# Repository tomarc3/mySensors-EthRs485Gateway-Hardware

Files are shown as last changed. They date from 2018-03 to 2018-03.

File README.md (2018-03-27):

# mySensors-EthRs485Gateway-Hardware

The mySensors-EthRs485Gateway-Hardware is a mySensors compatible Ethernet / RS485 gateway that is designed to fit in a DIN rail enclosure.

The PCB dimensions are designed to fit in a [CAMDENBOSS CNMB/2/KIT DIN](http://camdenboss.com/enclosures/din-rail-enclosures/cnmb-solid-top-kit) rail enclosure - with a litte mod... ;) 

The firmware that works with this gateway can be found at https://github.com/tomarc3/mySensors-EthRs485Gateway

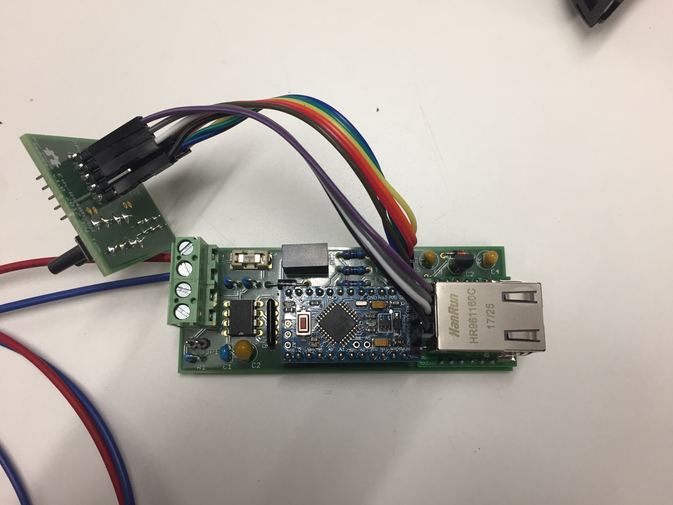
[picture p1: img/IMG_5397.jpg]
Top view

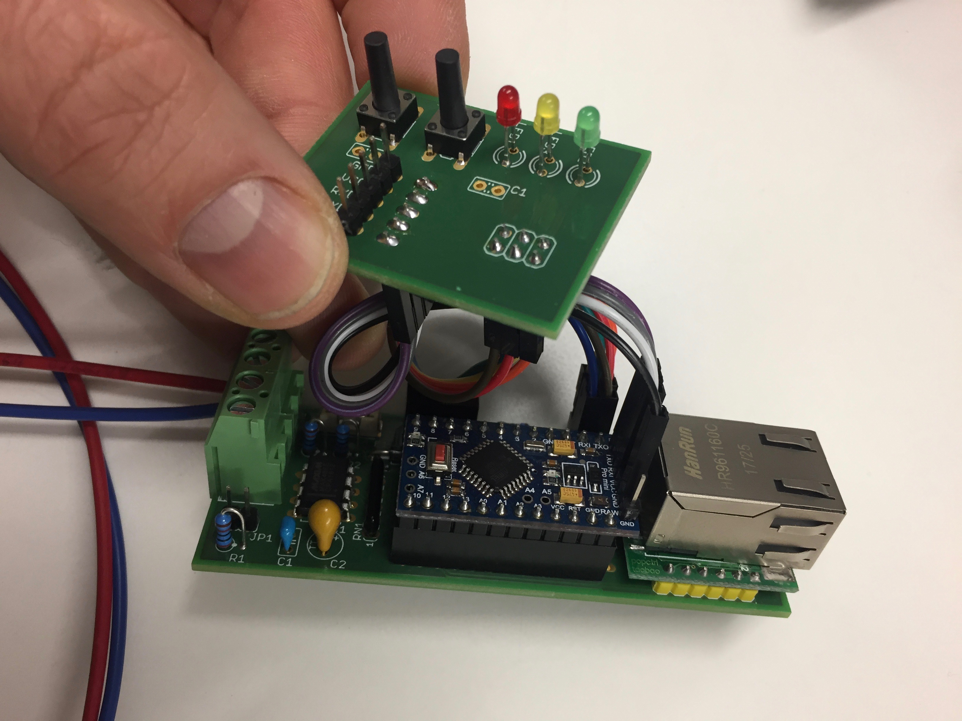
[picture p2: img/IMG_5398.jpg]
Side view


The front panel:
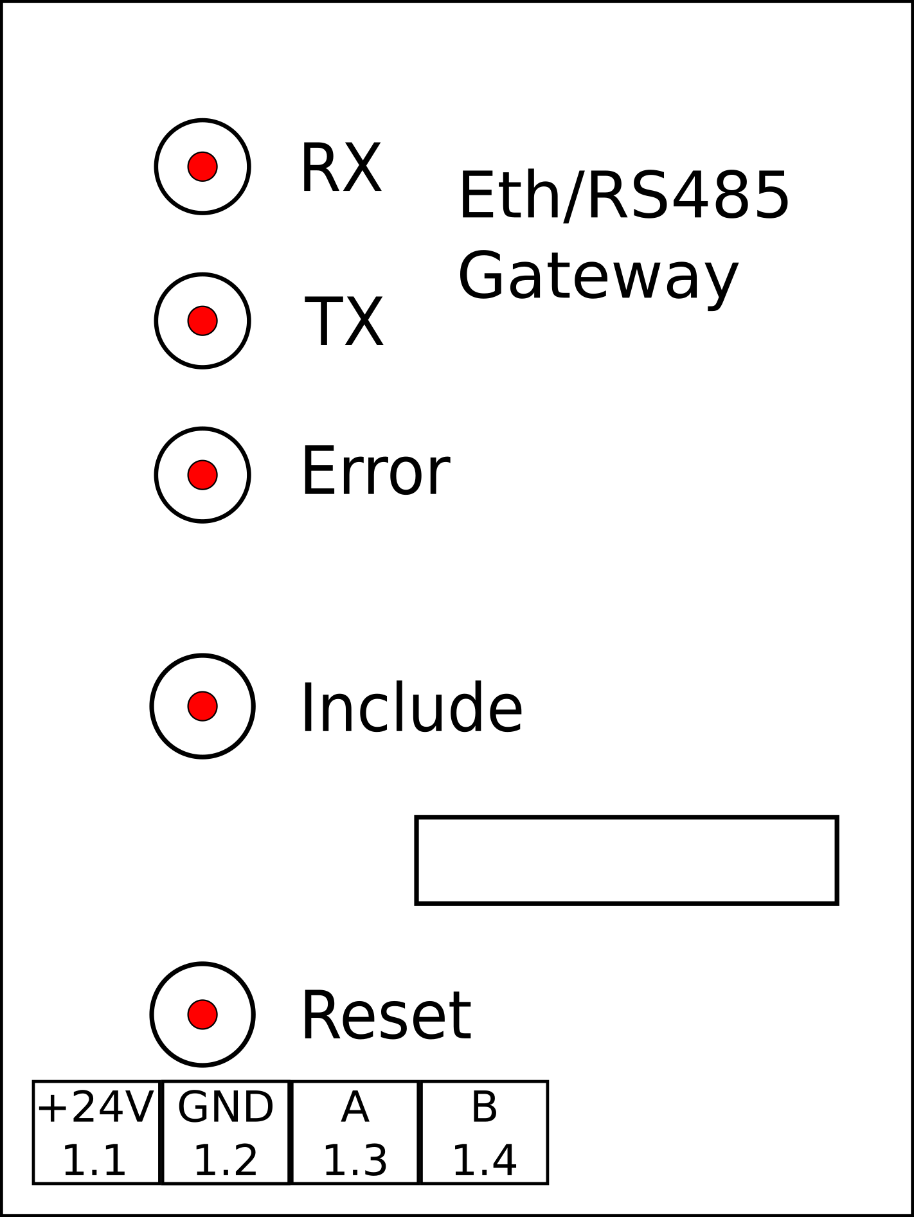
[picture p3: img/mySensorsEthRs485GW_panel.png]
Front panel


## Refereneces
* https://github.com/tomarc3/mySensors-EthRs485Gateway - the firmware built to run on this hardware
* https://www.mysensors.org - mySensors home page
* https://www.mysensors.org/build/rs485 - the example sketch that served as reference for this project 
* http://camdenboss.com/enclosures/din-rail-enclosures/cnmb-solid-top-kit - CAMDENBOSS CNMB/2/KIT DIN rail enclosure

## Change Log
* v1.0 ()
   Initial version.

## License
Copyright 2018 by Tom Kocher.

This documentation describes Open Hardware and is licensed under the CERN OHL v.1.2.

You may redistribute and modify this documentation under the terms of the CERN OHL v.1.2. (http://ohwr.org/cernohl). This documentation is distributed WITHOUT ANY EXPRESS OR IMPLIED WARRANTY, INCLUDING OF MERCHANTABILITY, SATISFACTORY QUALITY AND FITNESS FOR A PARTICULAR PURPOSE. Please see the CERN OHL v.1.2 for applicable conditions

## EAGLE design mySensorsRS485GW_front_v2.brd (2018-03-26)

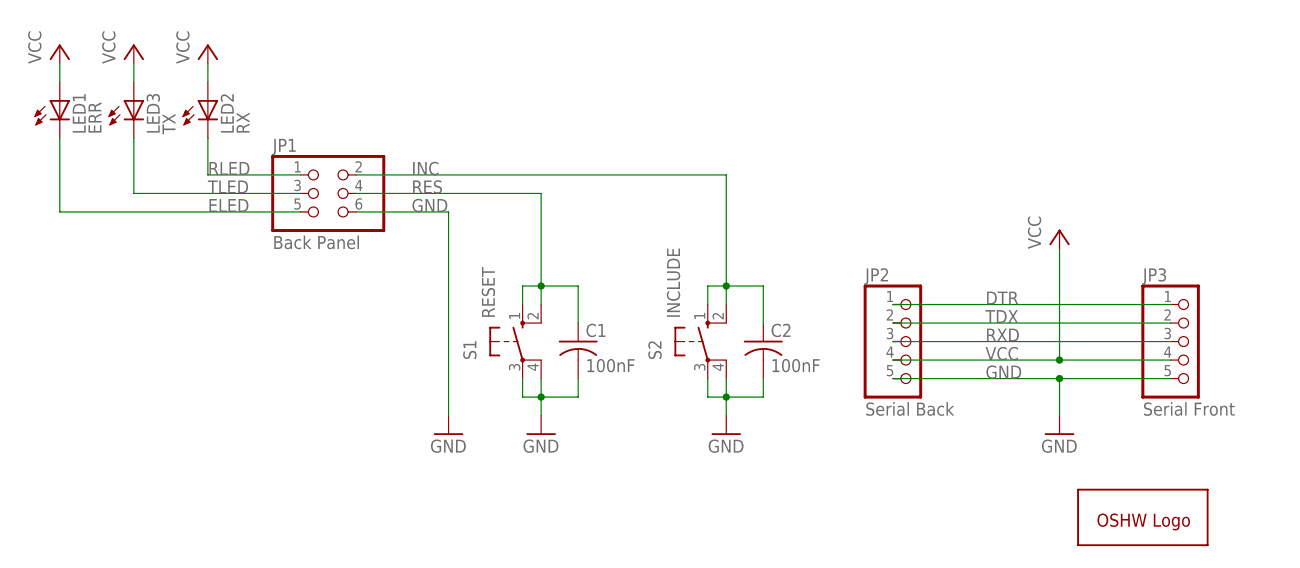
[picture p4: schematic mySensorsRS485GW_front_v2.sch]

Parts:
C1, C2: 100nF; C025-025X050
GOLD_ORB_SM1: OSHWLOGOLOGO5MM; OSHW_5MM
JP1: Back Panel; 2X03
JP2: Serial Back; 1X05
JP3: Serial Front; 1X05
LED1: ERR; LED3MM
LED2: RX; LED3MM
LED3: TX; LED3MM
S1: RESET; B3F-10XX
S2: INCLUDE; B3F-10XX

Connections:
DTR: JP2.1, JP3.1
ELED: JP1.5, LED1.K (C)
GND: C1.2, C2.2, JP1.6, JP2.5, JP3.5, S1.3, S1.4 (P1), S2.3, S2.4 (P1)
INC: C2.1, JP1.2, S2.1 (S), S2.2 (S1)
RES: C1.1, JP1.4, S1.1 (S), S1.2 (S1)
RLED: JP1.1, LED2.K (C)
RXD: JP2.3, JP3.3
TDX: JP2.2, JP3.2
TLED: JP1.3, LED3.K (C)
VCC: JP2.4, JP3.4, LED1.A, LED2.A, LED3.A

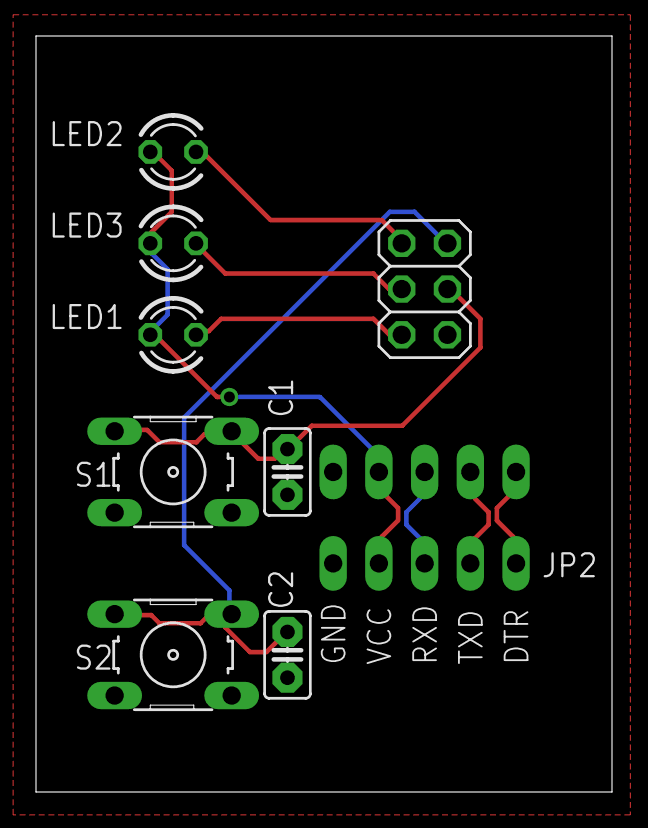
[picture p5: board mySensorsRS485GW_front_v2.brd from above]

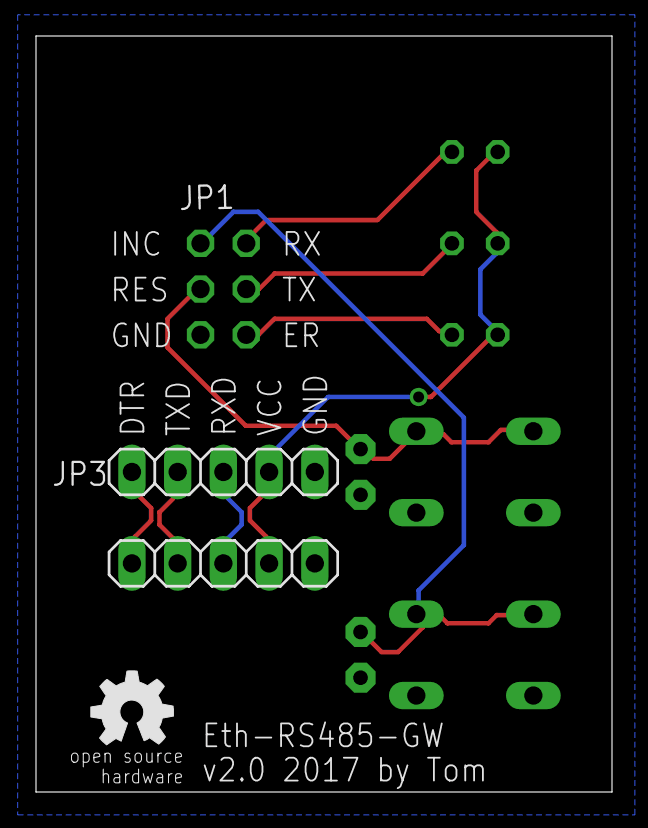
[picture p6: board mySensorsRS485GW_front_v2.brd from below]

Board: 2 copper layers, 32.0 x 42.0 mm, 11 parts (3 on the bottom side), 10 nets.

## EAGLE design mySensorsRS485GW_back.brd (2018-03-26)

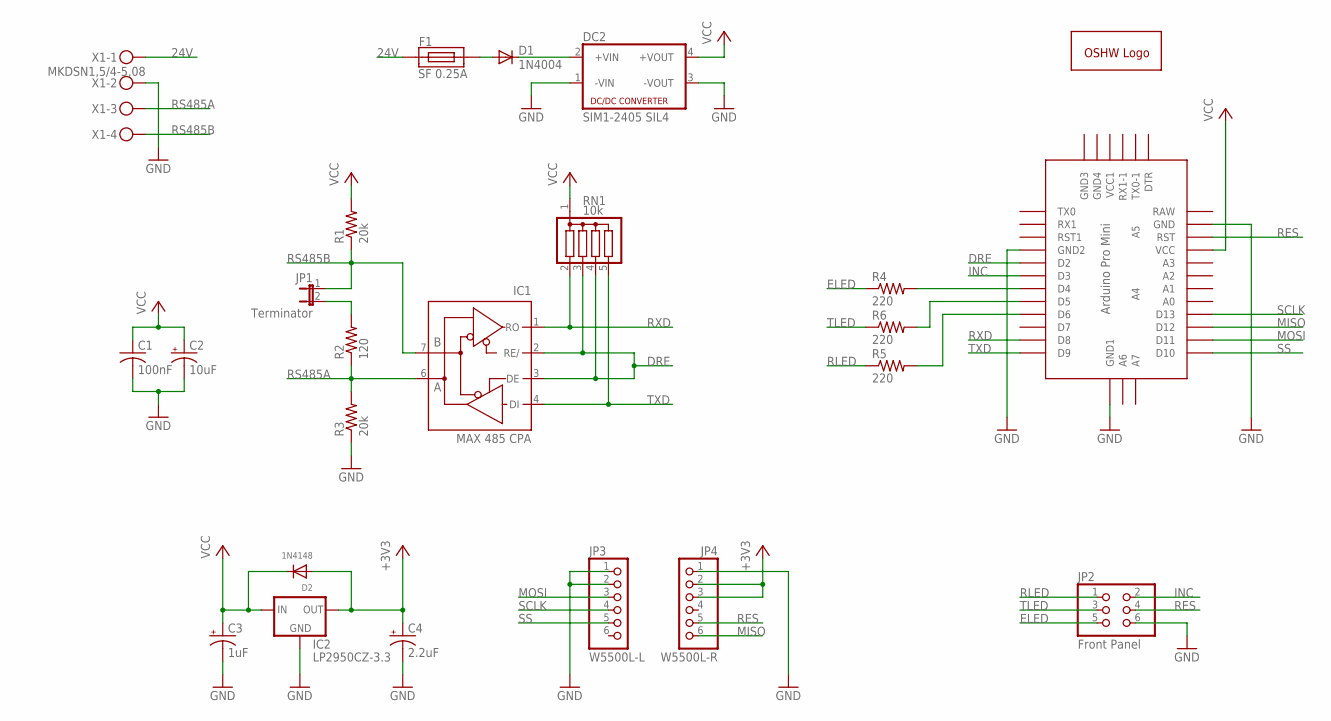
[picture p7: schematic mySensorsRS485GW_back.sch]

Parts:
C1: 100nF; C025-025X050
C2: 10uF; TT2D5
C3: 1uF; TT2D5
C4: 2.2uF; TT2D5
D1: 1N4004; DO41-10
D2: 1N4148; DO-1N4148
DC2: SIM1-2405 SIL4; NME
F1: SF 0.25A; NANO2_SMF_FUSEBLOCK
GOLD_ORB_SM1: OSHWLOGOLOGO5MM; OSHW_5MM
IC1: MAX 485 CPA; DIL08
IC2: LP2950CZ-3.3; TO92
JP1: Terminator; JP1
JP2: Front Panel; 2X03
JP3: W5500L-L; 1X06
JP4: W5500L-R; 1X06
R1, R3: 20k; 0207/2V
R2: 120; 0207/2V
R4, R5, R6: 220; 0207/7
RN1: 10k; SIL5
U$1: ABK-PRO-MINI
X1: MKDSN1,5/4-5,08

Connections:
24V: F1.1, X1.1
+3V3: C4.+, D2.A, IC2.1 (OUT), JP4.2, JP4.3
DRE: IC1.2 (RE/), IC1.3 (DE), RN1.3, RN1.4, U$1.D2
ELED: JP2.5, R4.1
GND: C1.2, C2.-, C3.-, C4.-, DC2.1 (-VIN), DC2.3 (-VOUT), IC1.5 (GND), IC2.2 (GND), JP2.6, JP3.1, JP3.2, JP4.1, R3.1, U$1.GND, U$1.GND1 (GND2), U$1.GND4 (GND1), X1.2
INC: JP2.2, U$1.D3
MISO: JP4.6, U$1.D12
MOSI: JP3.3, U$1.D11
unnamed: R4.2, U$1.D4
unnamed: D1.A, F1.2
unnamed: D1.C, DC2.2 (+VIN)
unnamed: R6.2, U$1.D5
unnamed: R5.2, U$1.D6
unnamed: JP1.2, R2.2
RES: JP2.4, JP4.5, U$1.RST
RLED: JP2.1, R5.1
RS485A: IC1.6 (A), R2.1, R3.2, X1.3
RS485B: IC1.7 (B), JP1.1, R1.1, X1.4
RXD: IC1.1 (RO), RN1.2, U$1.D8
SCLK: JP3.4, U$1.D13
SS: JP3.5, U$1.D10
TLED: JP2.3, R6.1
TXD: IC1.4 (DI), RN1.5, U$1.D9
VCC: C1.1, C2.+, C3.+, D2.C, DC2.4 (+VOUT), IC1.8 (VCC), IC2.3 (IN), R1.2, RN1.1, U$1.VCC

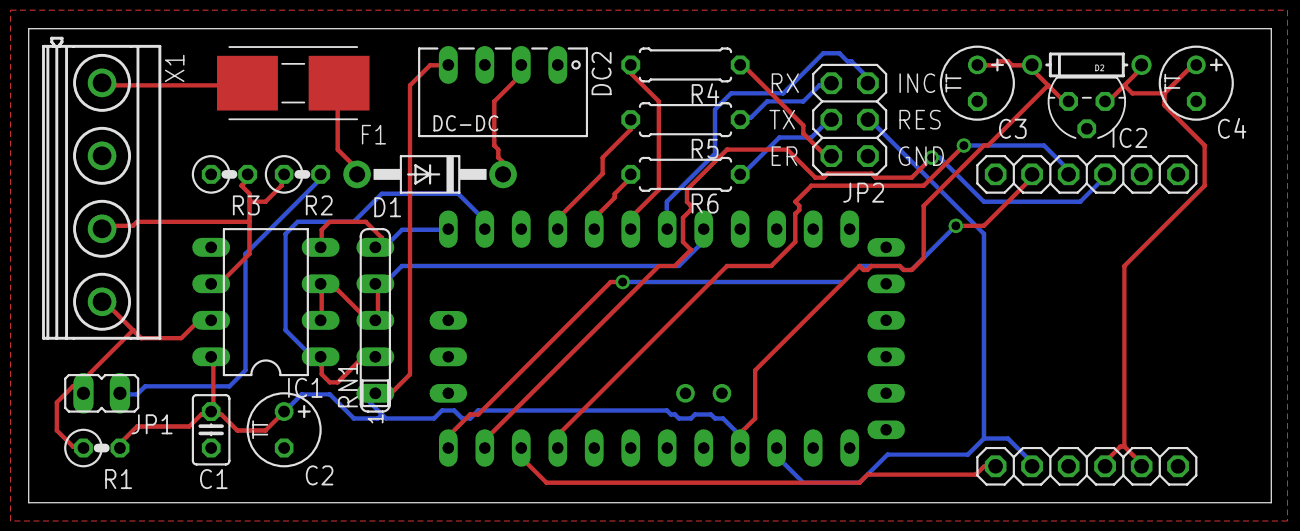
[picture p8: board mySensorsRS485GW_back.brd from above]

Board: 2 copper layers, 86.5 x 33.0 mm, 24 parts (1 on the bottom side), 24 nets.
